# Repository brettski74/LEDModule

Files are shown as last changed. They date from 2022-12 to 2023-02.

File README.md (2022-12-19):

# LED Module
This is a design for a simple 3-LED lighting module that I designed for using in my 3D
printer enclosure. It uses CREE J2835 Series LEDs and runs on 11-14V input voltage, so
should run just fine off the 12V supply of many 3D printers.s

The design uses a simple two-transistor current regulator to set the LED current and
hold it steady across the entire input voltage range. The three LEDs are placed in
series and the LED current is set by R2, R3, R4 and R5. Multiple resistors are used to
handle the power dissipation without resorting to more expensive higher power SMD
resistors. Typical setup is to use 3 x 91k resistors for R2, R3 and R4 and leave R5
open. This gives a roughly 30 ohm shunt which gives a roughly 20mA LED current. If you
want to set a different LED current, you can alter the resistors used for R2, R3, R4
and R5, which are placed in parallel and form the shunt resistor of the regulator. The
LED current can be approximated by the formula:

    0.6V / Rshunt

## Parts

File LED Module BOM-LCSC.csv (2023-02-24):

LCSC Part Number | Manufacture Part Number | Manufacturer | Package | Customer # | Description | RoHS | Order Qty. | Min\Mult Order Qty. | Unit Price | Order Price | Product Link
C210323 | HL-AM-2835D1W-S1-08-HR3 | HONGLITRONIC(Hongli Zhihui (HONGLITRONIC)) | 2835(mm) |  | 150mA 65lm 6000K Yellow Diffused -40℃~+85℃ Positive post White light 120° 510mW 3.4V 2835(mm) Light Emitting Diodes (LED) ROHS | yes | 3 | 50 | 0.0209 | 1.05 | https://assets.lcsc.com/images/lcsc/96x96/20180914_HONGLITRONIC-Hongli-Zhihui--HONGLITRONIC--HL-AM-2835D1W-S1-08-HR3_C210323_front.jpg
C2836076 | BC847DW 1Ft | CBI | SOT-363 |  | 15nA 45V 200mW 100mA 100MHz 300mV@100mA,5mA 2 NPN +150℃@(Tj) SOT-363 Bipolar Transistors - BJT ROHS | yes | 1 | 20 | 0.0377 | 0.75 | https://assets.lcsc.com/images/lcsc/96x96/20230129_CBI-BC847DW-1Ft_C2836076_front.jpg
C2930434 | FRC1206F91R0TS | FOJAN | 1206 |  | 250mW Thick Film Resistors 200V ±1% -55℃~+155℃ 91Ω 1206 Chip Resistor - Surface Mount ROHS | yes | 3 | 100 | 0.0045 | 0.45 | https://assets.lcsc.com/images/lcsc/96x96/20230122_FOJAN-FRC1206F91R0TS_C2930434_front.jpg
C2906980 | FRC0603F1003TS | FOJAN | 603 |  | 100mW Thick Film Resistors 50V ±100ppm/℃ ±1% -55℃~+155℃ 100kΩ 0603 Chip Resistor - Surface Mount ROHS | yes | 1 | 100 | 0.0014 | 0.14 | https://assets.lcsc.com/images/lcsc/96x96/20230121_FOJAN-FRC0603F1003TS_C2906980_front.jpg
C713511 | TCC0805X5R105M250FT | CCTC | 805 |  | 25V 1uF X5R ±20% 0805 Multilayer Ceramic Capacitors MLCC - SMD/SMT ROHS | yes | 1 | 100 | 0.0093 | 0.93 | https://assets.lcsc.com/images/lcsc/96x96/20230202_CCTC-TCC0805X5R105M250FT_C713511_front.jpg
C2905019 | PH-2PWB | DEALON | SMD,P=2mm |  | 1x2P 1 2mm Male pin 2 -25℃~+85℃ 2A Surface Mount SMD,P=2mm Wire To Board / Wire To Wire Connector ROHS | yes | 1 | 20 | 0.0368 | 0.74 | https://assets.lcsc.com/images/lcsc/96x96/20230129_DEALON-PH-2PWB_C2905019_front.jpg

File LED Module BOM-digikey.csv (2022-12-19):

Index | Manufacturer Part Number | Manufacturer Name | Description | Requested Quantity 1 | Pack Quantity 1 | Pack Type 1 | Digi-Key Part Number 1 | Unit Price 1 | Extended Price 1 | Minimum Order Quantity 1 | Requested Part Number | Datasheet | Reference Designator | Image
1 | JE2835AWT-00-0000-0B0A0HG765E | CreeLED, Inc. | LED WHT CRI 80 6500K JE2835 3V | 3 | 3 | Cut Tape (CT) | JE2835AWT-00-0000-0B0A0HG765ECT-ND | 0.16 | $0.48 | 1 | JE2835AWT-00-0000-0B0A0HG765ECT-ND | https://media.digikey.com/pdf/Data%20Sheets/CREE%20Power/J_Series_2835_3-V_Rev2C_2022.pdf | D1,D2,D3 | https://media.digikey.com/Photos/Cree%20Photos/Cree-J-Series-2835.jpg
2 | BC847BSHE3-TP | Micro Commercial Co | DUAL NPN SMALL SIGNAL TRANSISTOR | 1 | 1 | Cut Tape (CT) | 353-BC847BSHE3-TPCT-ND | 0.36 | $0.36 | 1 | 353-BC847BSHE3-TPCT-ND | https://www.mccsemi.com/pdf/Products/BC847BSHE3(SOT-363).pdf | Q1
3 | RMCF1206FT91R0 | Stackpole Electronics Inc | RES 91 OHM 1% 1/4W 1206 | 3 | 3 | Cut Tape (CT) | RMCF1206FT91R0CT-ND | 0.16 | $0.48 | 1 | RMCF1206FT91R0CT-ND | https://www.seielect.com/catalog/sei-rmcf_rmcp.pdf | R2,R3,R4 | https://media.digikey.com/Renders/Stackpole%20Renders/1206.jpg
4 | 1775469-2 | TE Connectivity AMP Connectors | CONN HEADER SMD R/A 2POS 2MM | 1 | 1 | Cut Tape (CT) | A100080CT-ND | 1.36 | $1.36 | 1 | A100080CT-ND | https://www.te.com/commerce/DocumentDelivery/DDEController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 | J1 | https://media.digikey.com/Photos/Tyco%20Amp%20Photos/1775469-2.jpg
5 | RMCF0603FT100K | Stackpole Electronics Inc | RES 100K OHM 1% 1/10W 0603 | 1 | 1 | Cut Tape (CT) | RMCF0603FT100KCT-ND | 0.16 | $0.16 | 1 | RMCF0603FT100KCT-ND | https://www.seielect.com/catalog/sei-rmcf_rmcp.pdf | R1 | https://media.digikey.com/Renders/Stackpole%20Renders/0603.jpg
6 | CL21B105KOFNNNE | Samsung Electro-Mechanics | CAP CER 1UF 16V X7R 0805 | 1 | 1 | Cut Tape (CT) | 1276-1026-1-ND | 0.15 | $0.15 | 1 | CL21B105KOFNNNE | http://www.samsungsem.com/kr/support/product-search/mlcc/CL21B105KOFNNNE.jsp | C1 | https://media.digikey.com/Renders/Samsung%20Electro-Mechanics%20America/Ceramic-Capacitor-CL-Series.jpg

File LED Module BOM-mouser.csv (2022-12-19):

Mfr Part Number | Quantity 1 | Mouser Part Number | Description | Price | Datasheet URL | Reference Designator
JE2835BWT-N-U50GA0000-N0000001 | 3 | 941-JE2835BWTNU50GAN | Mid-Power LEDs - Multi-Color Mid-Power LEDs - White White 5000 K, CRI-90 2835 Size, N Class | $0.138 | https://www.mouser.com/catalog/additional/SMART_Modular_Technologies_06092021_J_Series_2835_LEDs_Promo.pdf | D1,D2,D3
BC847BSHE3-TP | 1 | 833-BC847BSHE3-TP | Bipolar Transistors - BJT Bipolar Transistors - BJT | $0.317 | https://www.mouser.com/datasheet/2/258/BC847BSHE3_SOT_363_-2941301.pdf | Q1
ERJ-P08F9102V | 3 | 667-ERJ-P08F9102V | Thick Film Resistors - SMD Thick Film Resistors - SMD 1206 91Kohms 0.66W 1% AEC-Q200 | $0.373 | https://www.mouser.com/datasheet/2/315/AOA0000C331-1141874.pdf | R2,R3,R4
AC0603FR-07100KL | 1 | 603-AC0603FR-07100KL | Thick Film Resistors - SMD Thick Film Resistors - SMD 100 kOhms 100mW 0603 1% AEC-Q200 | $0.138 | https://www.mouser.com/datasheet/2/447/PYu_AC_51_RoHS_L_9-3005297.pdf | J1
1775469-2 | 1 | 571-1775469-2 | Headers & Wire Housings Headers & Wire Housings 2 POS HDR R/A SMT 2.0mm | $1.08 | https://www.mouser.com/datasheet/2/418/8/ENG_CD_1775469_A6-2019656.pdf | R1
CL21A106KOQNNNE | 1 | 187-CL21A106KOQNNNE | Multilayer Ceramic Capacitors MLCC - SMD/SMT Multilayer Ceramic Capacitors MLCC - SMD/SMT 10uF+/-10% 16V X5R 2 0805 | $0.138 | https://www.mouser.com/datasheet/2/585/MLCC-1837944.pdf | C1

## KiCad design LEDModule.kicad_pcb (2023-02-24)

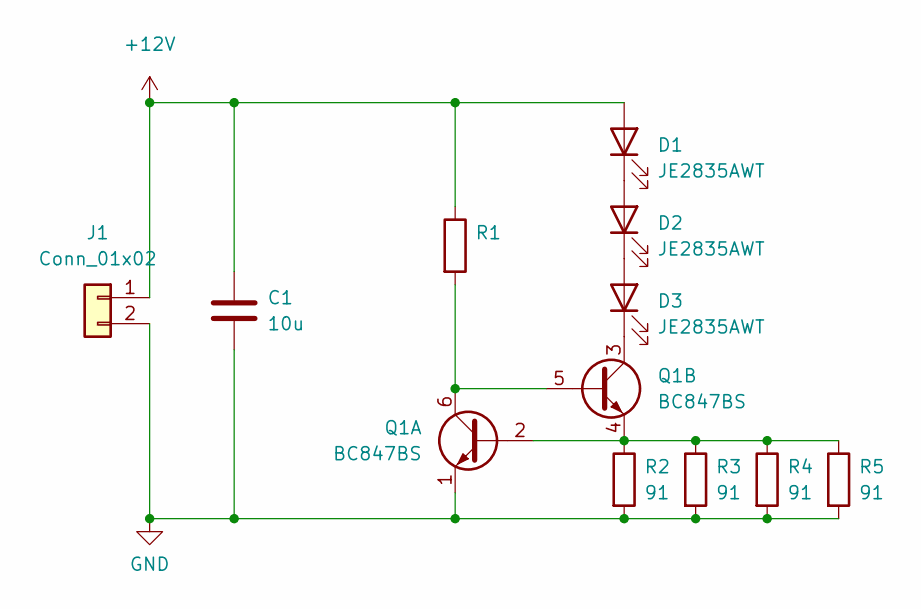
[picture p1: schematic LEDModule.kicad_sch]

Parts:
C1: 10u; C_0805_2012Metric
D1, D2, D3: JE2835AWT; LED_Cree-J-Series
J1: Conn_01x02; TE-HPI-1x2x2mm-1775469-2
Q1: BC847BS; SOT-363_SC-70-6
R1: (no value)
R2, R3, R4, R5: 91; R_1206_3216Metric

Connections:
+12V: C1.1, D1.2 (A), J1.1, R1.1
GND: C1.2, J1.2, Q1.1 (E1), R2.2, R3.2, R4.2, R5.2
unnamed: D1.1 (K), D2.2 (A)
unnamed: D2.1 (K), D3.2 (A)
unnamed: D3.1 (K), Q1.3 (C2)
unnamed: Q1.2 (B1), Q1.4 (E2), R2.1, R3.1, R4.1, R5.1
unnamed: Q1.5 (B2), Q1.6 (C1), R1.2

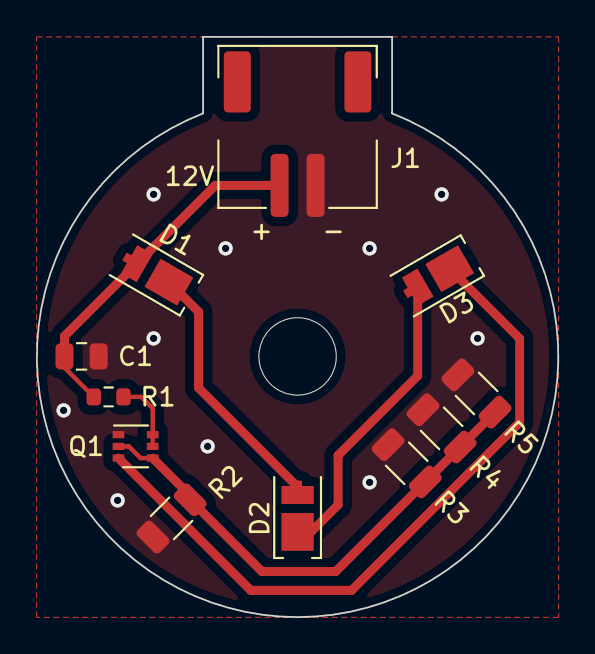
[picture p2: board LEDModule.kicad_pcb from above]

Board: 2 copper layers, 29.0 x 32.2 mm, 11 parts (0 on the bottom side), 7 nets.

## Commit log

2022-12-19 Initial commit of version 0.0 submitted to JLCPCB. Gerber files suitable for JLCPCB manufacture.
    [LED Module BOM-digikey.csv, LED Module BOM-mouser.csv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]
2023-02-24 Updated package size of R1. Added LCSC BOM.
    [LED Module BOM-LCSC.csv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]
